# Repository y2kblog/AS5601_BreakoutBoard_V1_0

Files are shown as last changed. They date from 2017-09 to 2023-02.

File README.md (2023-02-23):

# 12bit (4096P/R) 磁気式エンコーダAS5601 Breakout Board

[English page](https://products.y2kb.com/en/as5601/latest/)

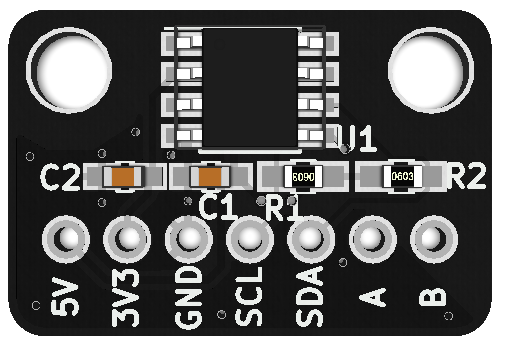
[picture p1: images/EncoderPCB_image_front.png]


## 概要

12bit (4096P/R) 分解能の磁気式アブソリュートエンコーダ AS5601 (ams AG製) を2.54mmピッチに変換する基板です。ネオジム磁石を同梱。  
5V、3.3V、GNDの電源ピンとI2C、A/B相インクリメンタル出力のピンが出ています。電源電圧は5Vもしくは3.3Vです。  
**※AS5600との違いはAS5600の出力方式がアナログ/PWM出力であるのに対し、AS5601はA/B相のインクリメンタル出力である点です。**

### AS5601の特徴
- 4096P/R の高分解能 (インクリメンタル出力は最大2048ppr)
- 磁気式のため非接触で角度計測が可能であり、信頼性と耐久性に優れている
- インターフェイス：I2C、インクリメンタル出力、PUSHピン
- I2C：設定レジスタにアクセスでき、角度の読み取りや動作設定が可能
- インクリメンタル出力：8ppr～2048pprの分解能設定が可能なA/B相の直交出力
- サンプリング時間：150μs
- AS5601とネオジム磁石の軸中心が1mm程度ずれても値の読み取りが可能

### 基板仕様
- 基板サイズ：横20mm×縦13.5ｍｍ
- 基板マウント用穴：15mmピッチ、M3×2穴
- 電源電圧に5Vを供給する場合は3.3Vピンをオープンに、3.3Vを供給する場合は5Vピンにも3.3Vを供給してください。
- PUSHピンは接続されていないためアクセスできません

## 販売  
[スイッチサイエンス委託販売ページ](https://www.switch-science.com/catalog/3494/)  
※大量注文や在庫に関する問い合わせは[こちら](mailto:info.y2kb@gmail.com)までご連絡ください。  

## 内容物
- AS5601 Breakout Board 本体
- エンコーダ用ネオジム磁石

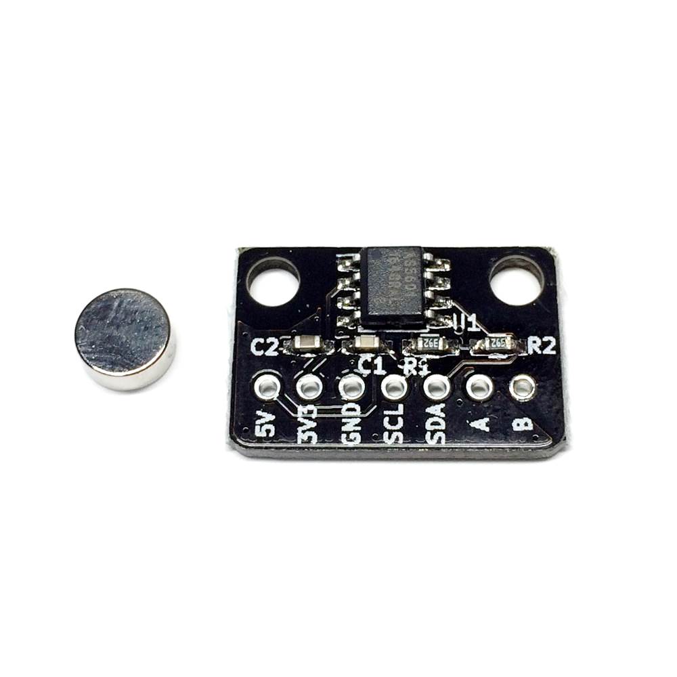
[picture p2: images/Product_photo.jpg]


### 回路図  
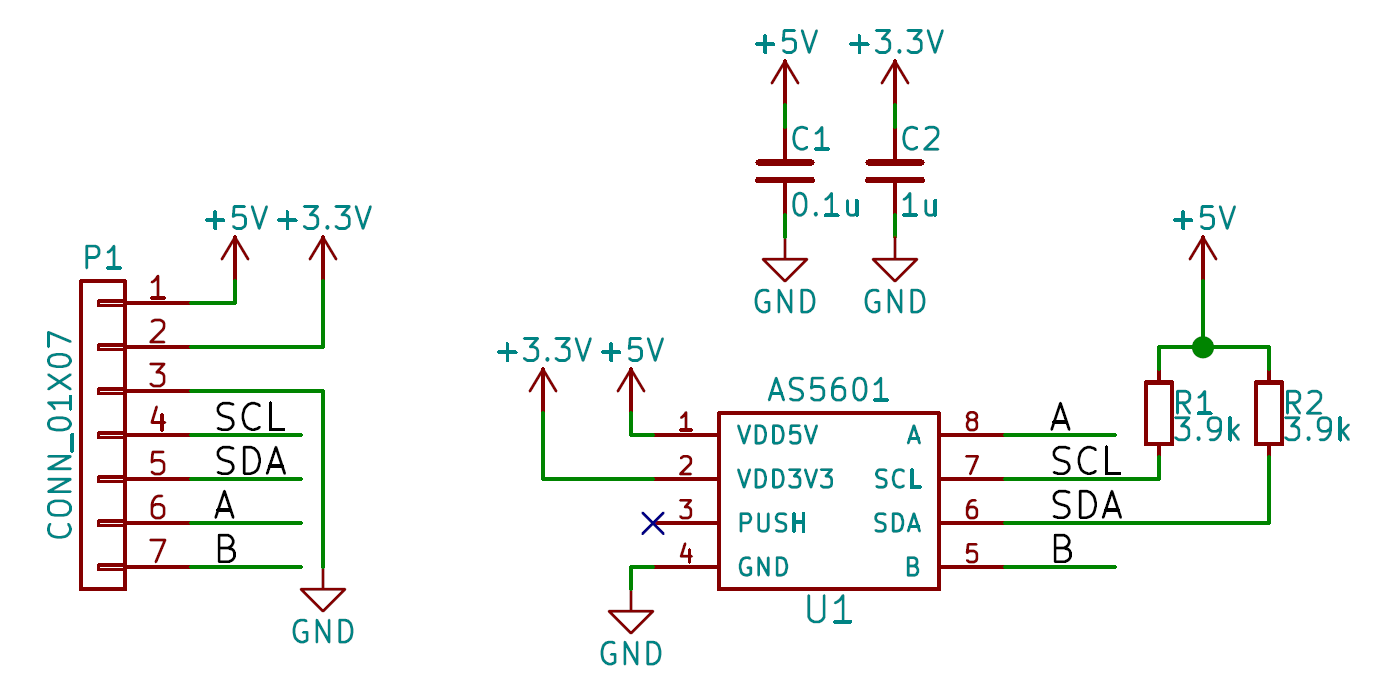
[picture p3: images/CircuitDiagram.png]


### 寸法  
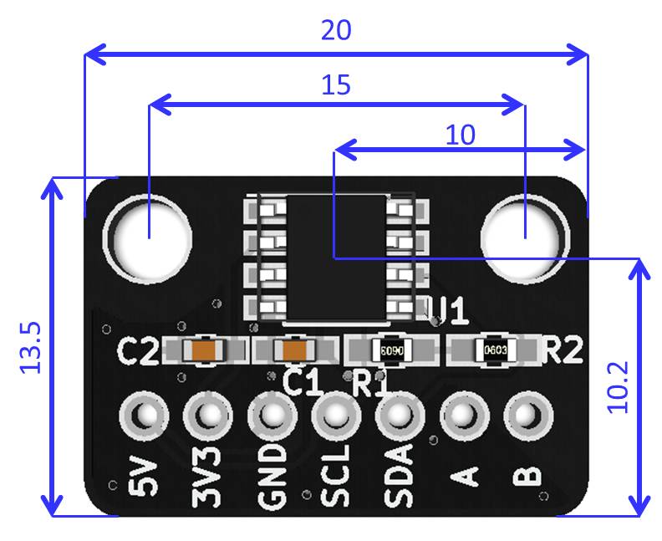
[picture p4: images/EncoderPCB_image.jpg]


## 取付方法
1. 同梱のネオジム磁石を回転体の軸中心に取り付けます
2. AS5601の中心とネオジム磁石の中心が合うよう基板を固定部に取り付けます

**取付例**  
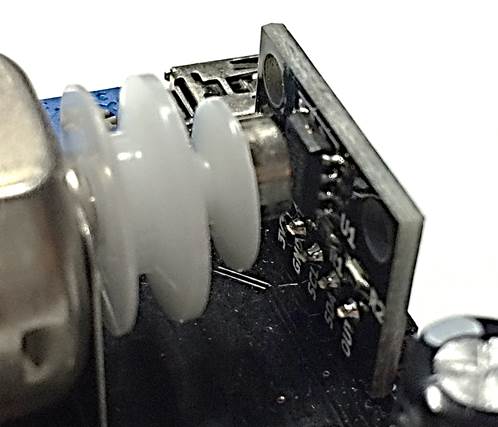
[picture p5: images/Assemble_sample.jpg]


## Arduinoによるプログラム例  

### I2Cによる角度の取得  
#### 配線図  
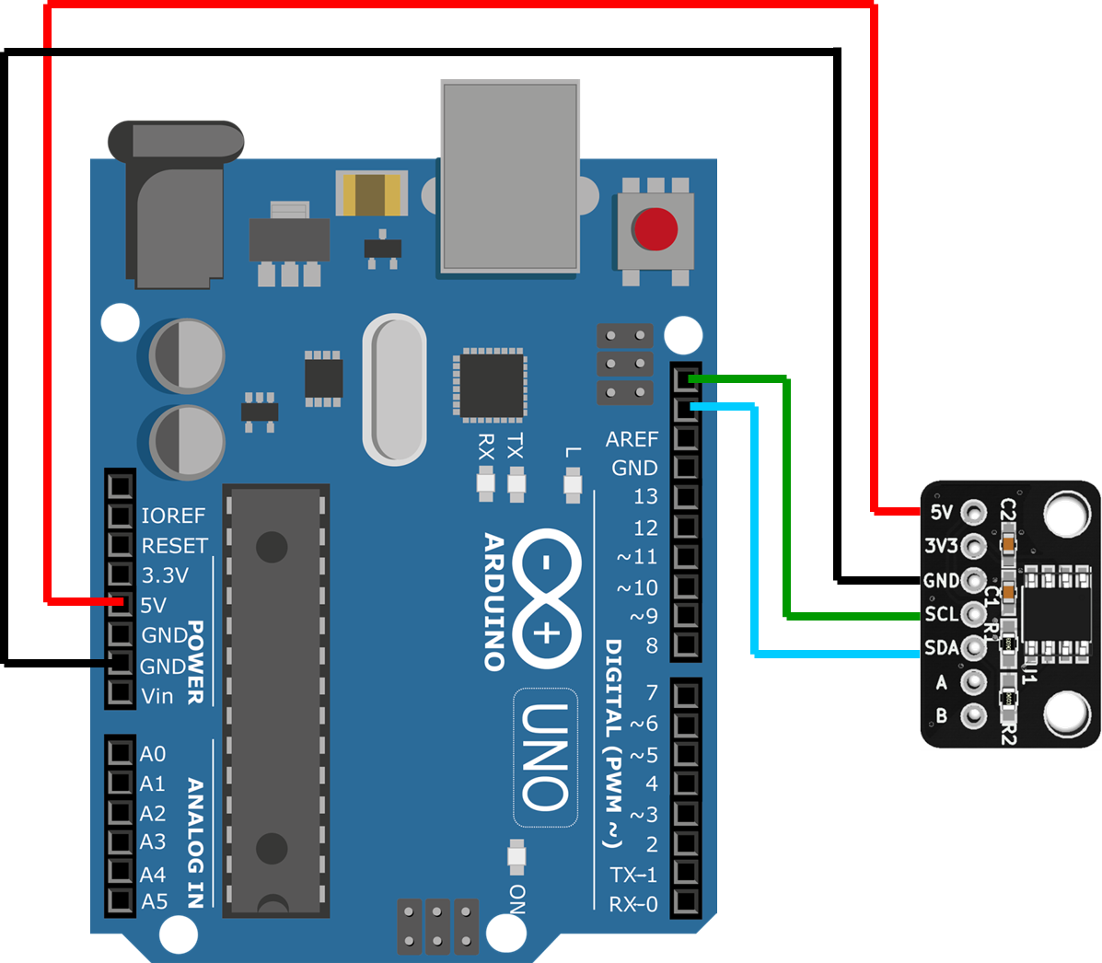
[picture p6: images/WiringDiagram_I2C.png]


#### [ソースファイル](https://github.com/y2kblog/AS5601_BreakoutBoard_V1_0/blob/master/SampleCode/Arduino/I2C_SampleCode/I2C_SampleCode.ino)

<!--
#### ソースファイルのディレクトリ  
"SampleCode/Arduino/I2C_SampleCode/I2C_SampleCode.ino"
-->

#### ミニマムコード  

```cpp
#include <stdint.h>
#include <Wire.h>
#define AS5600_AS5601_DEV_ADDRESS      0x36
#define AS5600_AS5601_REG_RAW_ANGLE    0x0C

void setup() {
  // I2C init
  Wire.begin();
  Wire.setClock(400000);

  // Read RAW_ANGLE value from encoder
  Wire.beginTransmission(AS5600_AS5601_DEV_ADDRESS);
  Wire.write(AS5600_AS5601_REG_RAW_ANGLE);
  Wire.endTransmission(false);
  Wire.requestFrom(AS5600_AS5601_DEV_ADDRESS, 2);
  uint16_t RawAngle = 0;
  RawAngle  = ((uint16_t)Wire.read() << 8) & 0x0F00;
  RawAngle |= (uint16_t)Wire.read();
  // Raw angle value (0 ~ 4095) is stored in RawAngle
}

void loop() {
}
```

### インクリメンタル出力ピンを用いた角度の取得  
#### 配線図  
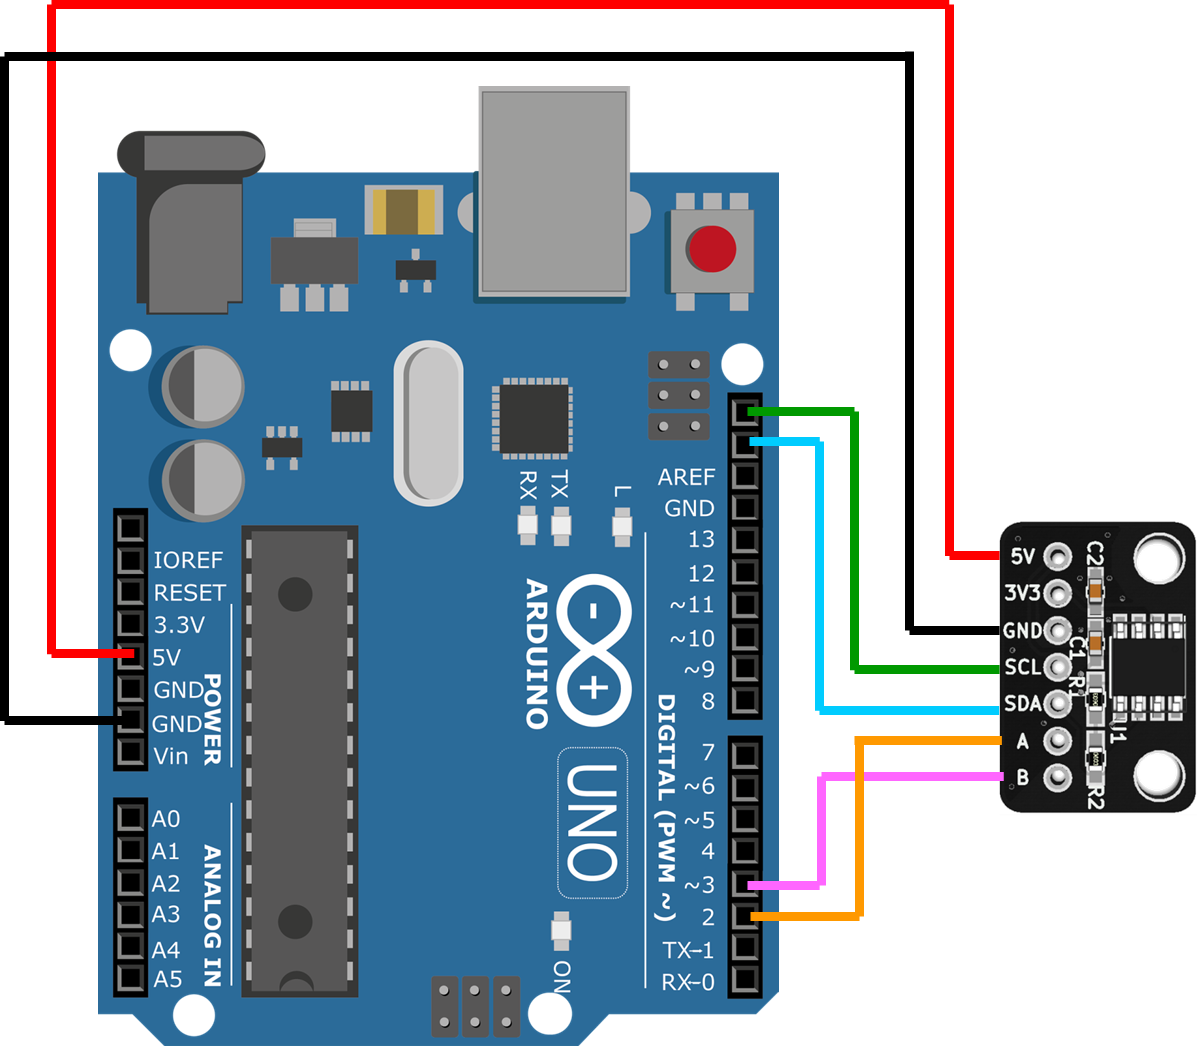
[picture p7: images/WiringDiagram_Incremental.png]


#### [ソースファイル](https://github.com/y2kblog/AS5601_BreakoutBoard_V1_0/blob/master/SampleCode/Arduino/Incremental_SampleCode/Incremental_SampleCode.ino)

<!--
#### ソースファイルのディレクトリ  
"SampleCode/Arduino/Incremental_SampleCode/Incremental_SampleCode.ino"
-->

#### ミニマムコード
```cpp
#include <stdint.h>
#include <Wire.h>
#define AS5600_AS5601_DEV_ADDRESS       0x36
#define AS5601_REG_ABN                  0x09

volatile int32_t EncoderCount;

void Encoder_GPIO_init(void) {
  DDRD  &= ~((1 << PD2) | (1 << PD3));  // Set PD2 and PD3 as input
  EICRA = 0b00000101; // Trigger event of INT0 and INT1 : Any Logic Change
  EIMSK = 0b00000011; // Enable interrupt INT0 and INT1
  sei();              //Enable Global Interrupt
}

// Encoder "A" pin logic change interrupt callback function
ISR(INT0_vect) {
  updateEncoderCount();
}

// Encoder "B" pin logic change interrupt callback function
ISR(INT1_vect) {
  updateEncoderCount();
}

void updateEncoderCount(void) {
  const static int8_t EncoderIndexTable[] =
    {0, -1, 1, 0,  1, 0, 0, -1,  -1, 0, 0, 1,  0, 1, -1, 0};
  static uint8_t EncoderPinState_Now, EncoderPinState_Prev = 0;

  EncoderPinState_Now = (PIND >> 2) & 0x03; // Bit1 : PD3 (Encoder B), Bit0 : PD2 (Encoder A)
  EncoderCount += EncoderIndexTable[EncoderPinState_Prev << 2 | EncoderPinState_Now];
  EncoderPinState_Prev = EncoderPinState_Now;
}

void Encoder_I2C_init(void) {
  // Set AS5601 resolution 2048ppr
  Wire.beginTransmission(AS5600_AS5601_DEV_ADDRESS);
  Wire.write(AS5601_REG_ABN);
  Wire.write(0b00001000);   // ABN(3:0)
  Wire.endTransmission();
  delay(1);
}

void setup() {
  // I2C init
  Wire.begin();
  Wire.setClock(400000);

  // Peripheral init
  Encoder_I2C_init();
  Encoder_GPIO_init();
}

void loop() {
  // Angle value (0 ~ 2047) is stored in EncoderCount
}
```

<!--
#### HAL (STM32)

**サンプルコード**

    // I2Cの初期化は終わっているとする

    #define AS5600_AS5601_DEV_ADDRESS      (0x36<<1)
    #define AS5600_AS5601_REG_RAW_ANGLE    0x0C

    uint8_t buf[2];
    HAL_I2C_Mem_Read(&hi2c, AS5600_AS5601_DEV_ADDRESS,
      AS5600_AS5601_REG_RAW_ANGLE, I2C_MEMADD_SIZE_8BIT,
      (uint8_t*)buf, 2, 1000);
    uint16_t RawAngle;
    RawAngle = (uint16_t) buf[0] << 8 | (uint16_t) buf[1];
    RawAngle &= 0x0FFF;
    // Raw angle value (0x0000~0x0FFF) is stored in RawAngle

### コンフィグのメモリへの焼き付け  

-->

### 設定レジスタの焼き付けによる分解能の固定

AS5601のデフォルトの分解能は8pprなので、初期状態ですと電源投入毎に分解能を設定する必要があります。
そこで、分解能を2048pprに設定後にBurn_Settingコマンドにより設定レジスタを焼くことで、電源を落として再度電源を投入しても起動時から2048pprに設定された状態で固定され、I2Cにより分解能等の設定情報を再設定する必要がなくなります。  
**※一度書き込むと以後分解能やフィルタ設定などを変更することはできなくなります。**

サンプルコードは[こちら](https://github.com/y2kblog/AS5601_BreakoutBoard_V1_0/blob/master/SampleCode/Arduino/burnConfig_SampleCode/burnConfig_SampleCode.ino)。

## 資料

- 2Dデータ(DXF)：<a href="https://github.com/y2kblog/AS5601_BreakoutBoard_V1_0/raw/master/PCB_source/dxf/AS5601_BreakoutBoard_V1_0_dxf.zip" download="">AS5601_BreakoutBoard_V1_0_dxf.zip</a>  
- 3Dデータ(STEP)：<a href="https://github.com/y2kblog/AS5601_BreakoutBoard_V1_0/raw/master/PCB_source/step/AS5601_BreakoutBoard_V1_0_step.zip" download="">AS5601_BreakoutBoard_V1_0_step.zip</a>  

## License
MIT License

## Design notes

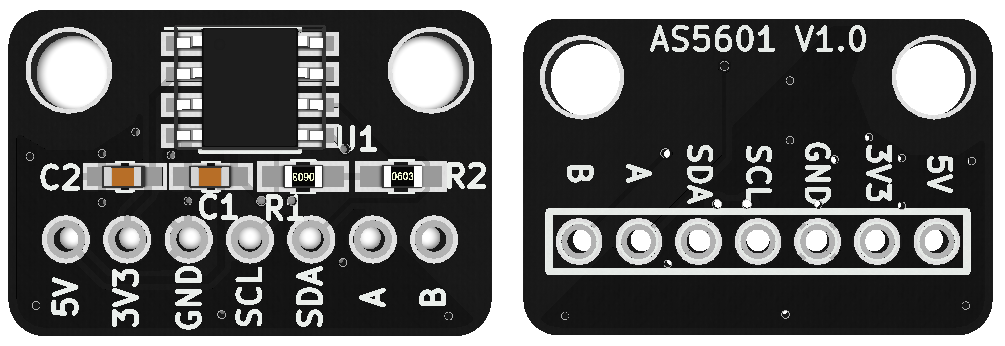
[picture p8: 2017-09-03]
images/EncoderPCB_image_BothSide.png

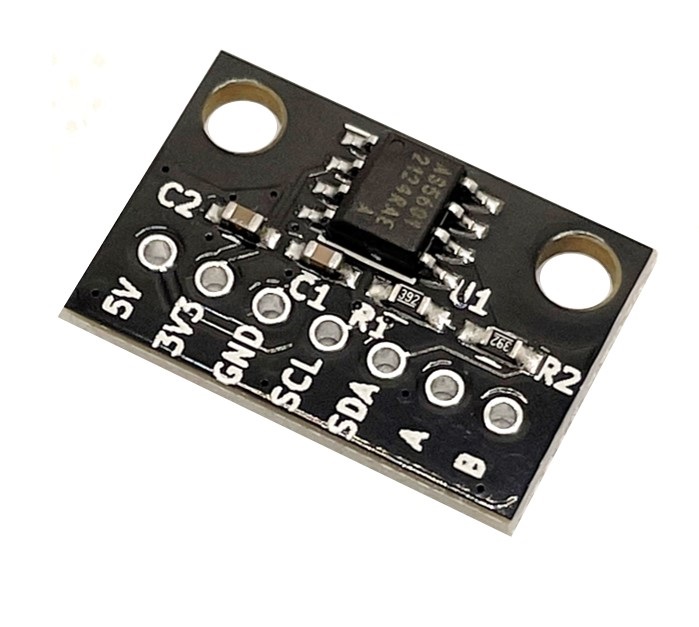
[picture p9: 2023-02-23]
images/product-image.jpg

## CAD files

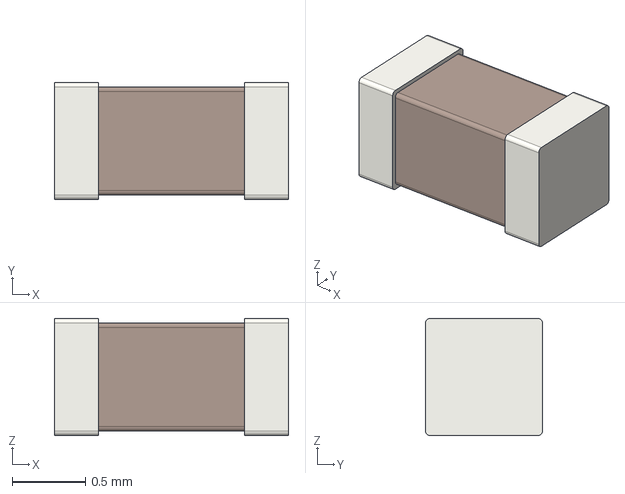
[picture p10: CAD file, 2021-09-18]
PCB_source/3d/C_0603_1608Metric.step
1.60 x 0.8 x 0.8 mm

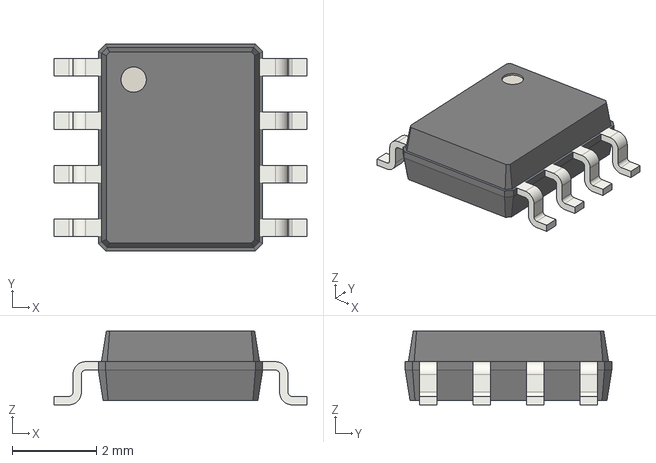
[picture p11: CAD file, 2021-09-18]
PCB_source/3d/SOIC-8_3.9x4.9mm_P1.27mm.step
6.00 x 4.90 x 1.75 mm

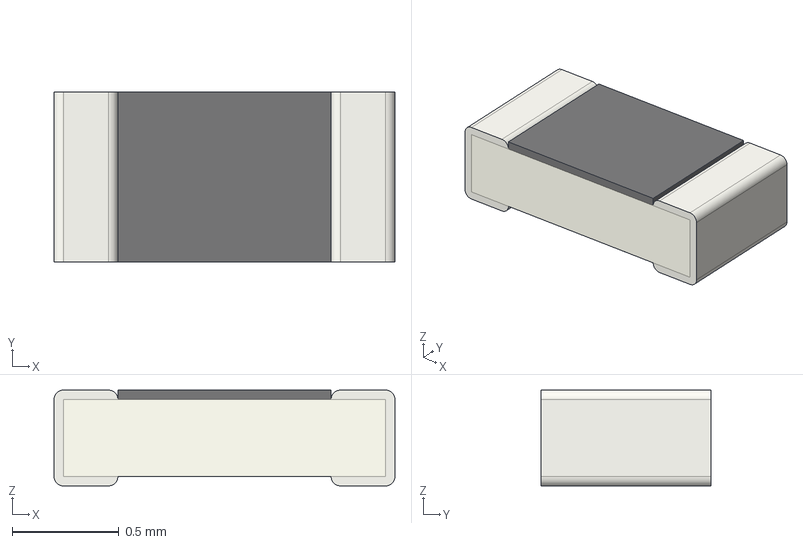
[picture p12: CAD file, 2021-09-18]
PCB_source/3d/R_0603_1608Metric.step
1.60 x 0.8 x 0.45 mm

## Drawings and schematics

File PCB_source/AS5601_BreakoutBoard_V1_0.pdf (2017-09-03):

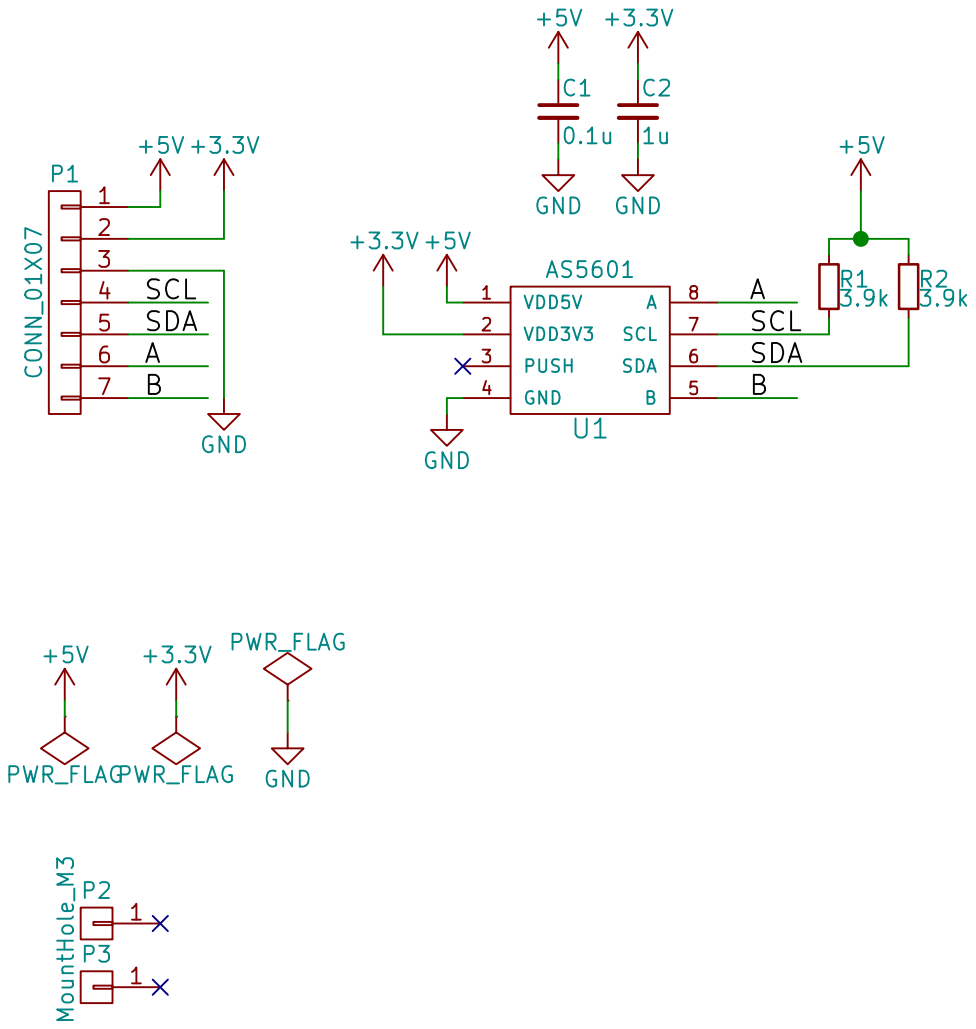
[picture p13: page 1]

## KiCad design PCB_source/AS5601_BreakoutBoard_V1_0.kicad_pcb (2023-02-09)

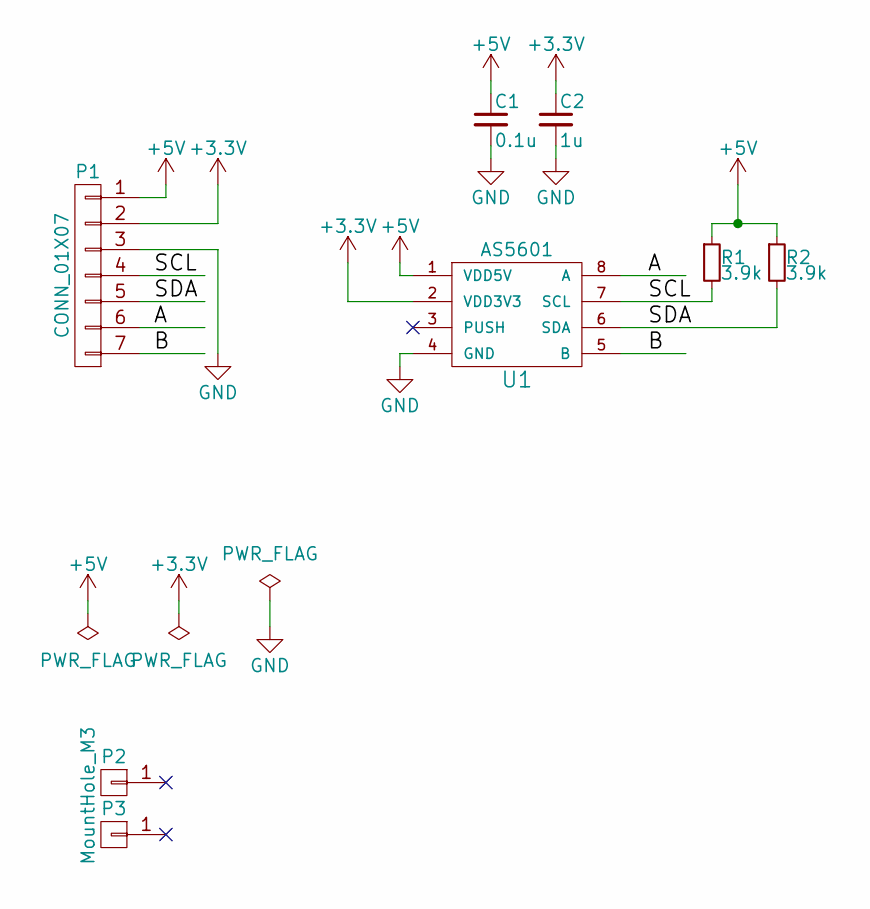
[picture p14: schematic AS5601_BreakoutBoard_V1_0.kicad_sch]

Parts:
C1: 0.1u; C_0603_HandSoldering
C2: 1u; C_0603_HandSoldering
P1: CONN_01X07; USER_SIL-7
P2, P3: MountHole_M3; MountingHole_3.2mm_M3
R1, R2: 3.9k; R_0603_HandSoldering
U1: AS5601; SOIC-8_3.9x4.9mm_Pitch1.27mm

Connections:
+3V3: C2.1, P1.2, U1.2 (VDD3V3)
+5V: C1.1, P1.1, R1.1, R2.1, U1.1 (VDD5V)
/A: P1.6, U1.8 (A)
/B: P1.7, U1.5 (B)
/SCL: P1.4, R1.2, U1.7 (SCL)
/SDA: P1.5, R2.2, U1.6 (SDA)
GND: C1.2, C2.2, P1.3, U1.4 (GND)

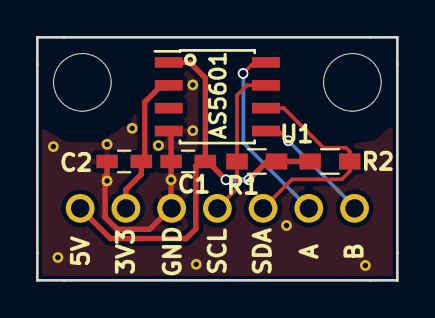
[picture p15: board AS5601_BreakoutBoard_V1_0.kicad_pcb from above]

Board: 2 copper layers, 20.0 x 13.5 mm, 19 parts (1 on the bottom side), 7 nets.

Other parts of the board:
11, 12, 21, 22, 31, 32, 41, 41#2, 42, 51, 52: USER_GNDvia

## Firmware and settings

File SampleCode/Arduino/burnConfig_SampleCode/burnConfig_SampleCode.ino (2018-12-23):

/* ----- Pin setting -----
   PC4 - Analog   4 - Encoder SDA
   PC5 - Analog   5 - Encoder SCL
   PD2 - Digital  2 - Encoder A - INT0
   PD3 - Digital  3 - Encoder B - INT1
*/

#include <stdint.h>
#include <Wire.h>
#define AS5600_AS5601_DEV_ADDRESS       0x36
#define AS5600_AS5601_REG_CONF          0x07
#define AS5600_AS5601_REG_STATUS        0x0B
#define AS5601_REG_ABN                  0x09
#define AS5600_AS5601_REG_BURN          0xFF

volatile int32_t EncoderCount;

void Encoder_GPIO_init(void) {
  DDRD  &= ~((1 << PD2) | (1 << PD3));  // Set PD2 andEncoder_burn_config PD3 as input
  EICRA = 0b00000101; // Trigger event of INT0 and INT1 : Any Logic Change
  EIMSK = 0b00000011; // Enable interrupt INT0 and INT1
  sei();              //Enable Global Interrupt
}

// Encoder "A" pin logic change interrupt callback function
ISR(INT0_vect) {
  updateEncoderCount();
}

// Encoder "B" pin logic change interrupt callback function
ISR(INT1_vect) {
  updateEncoderCount();
}

void updateEncoderCount(void) {
  const static int8_t EncoderIndexTable[] =
    {0, -1, 1, 0,  1, 0, 0, -1,  -1, 0, 0, 1,  0, 1, -1, 0};
  static uint8_t EncoderPinState_Now, EncoderPinState_Prev = 0;

  EncoderPinState_Now = (PIND >> 2) & 0x03; // Bit1 : PD3 (Encoder B), Bit0 : PD2 (Encoder A)
  EncoderCount += EncoderIndexTable[EncoderPinState_Prev << 2 | EncoderPinState_Now];
  EncoderPinState_Prev = EncoderPinState_Now;
}

void Encoder_I2C_init(void) {
  byte error;
  uint8_t data;

  // Read AS5601 status register
  Wire.beginTransmission(AS5600_AS5601_DEV_ADDRESS);
  Wire.write(AS5600_AS5601_REG_STATUS);
  Wire.endTransmission(false);
  Wire.requestFrom(AS5600_AS5601_DEV_ADDRESS, 1);
  data = Wire.read();
  data &= 0x38;
  /*
  if (data != 0x20)
  {
    Serial.print("Magnet error : ");
    if ( !(data & 0x20) )
      Serial.println("Magnet was not detected");
    if (data & 0x10)
      Serial.println("Magnet too weak");
    if (data & 0x08)
      Serial.println("Magnet too strong");
    Serial.println("Stop");
    for (;;);
  }
  else
    Serial.println("Magnet : OK");
    */

  // Set AS5601 resolution 2048ppr
  Serial.println("Change Encoder resolution 2048ppr");
  Wire.beginTransmission(AS5600_AS5601_DEV_ADDRESS);
  Wire.write(AS5601_REG_ABN);
  Wire.write(0b00001000);   // Resolution:2048ppr(ABN=0b1000)
  error = Wire.endTransmission();
  if (error){
    Serial.print("error=");Serial.println(error);
  }
  delay(1);

  // Write AS5601 conf
  Wire.beginTransmission(AS5600_AS5601_DEV_ADDRESS);
  Wire.write(AS5600_AS5601_REG_CONF);
  Wire.write(0b00000111);   // Watchdog Timer:Off(WD=0b0), Fast Filter Threshold:6LSBs(FTH = 0b001), Slow Filter:2x(SF = 0b11)
  error = Wire.endTransmission();
  if (error){
    Serial.print("error=");Serial.println(error);
  }
  delay(1);
}

///// CAUTION: One time programming!!! //////
void Encoder_burn_config(void) {
  byte error;
  // Burn conf
  Wire.beginTransmission(AS5600_AS5601_DEV_ADDRESS);
  Wire.write(AS5600_AS5601_REG_BURN);
  Wire.write(0x40);   // Burn_Setting = 0x40
  error = Wire.endTransmission();
  if (error){
    Serial.print("error=");Serial.println(error);
  }
  delay(1);
}

void setup() {
  // I2C init
  Wire.begin();
  Wire.setClock(400000);

  // Communication function init
  Serial.begin(115200);
  while (!Serial);

  // Peripheral init
  Encoder_I2C_init();
  Encoder_burn_config();  // CAUTION: One time programming!
  Encoder_GPIO_init();
}

void loop() {
  Serial.println(EncoderCount);
  delay(200);
}

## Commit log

2017-09-07 fix sample code bug
    [Arduino_AS5600_AS5601_SampleCode.ino]
2017-09-17 Add sample code using Incremental output
2017-09-22 Add circuit diagram
2018-05-28 Add burnConfig sample code
    [burnConfig_SampleCode.ino]
2021-09-18 add step and refactoring
    [AS5601_BreakoutBoard_V1_0-2021-09-18-11-56-55.sch, AS5601_BreakoutBoard_V1_0.dsn, AS5601_BreakoutBoard_V1_0.kicad_pcb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]
2023-02-09 kicad v6
    [AS5601_BreakoutBoard_V1_0.kicad_pcb, AS5601_BreakoutBoard_V1_0.kicad_sch]

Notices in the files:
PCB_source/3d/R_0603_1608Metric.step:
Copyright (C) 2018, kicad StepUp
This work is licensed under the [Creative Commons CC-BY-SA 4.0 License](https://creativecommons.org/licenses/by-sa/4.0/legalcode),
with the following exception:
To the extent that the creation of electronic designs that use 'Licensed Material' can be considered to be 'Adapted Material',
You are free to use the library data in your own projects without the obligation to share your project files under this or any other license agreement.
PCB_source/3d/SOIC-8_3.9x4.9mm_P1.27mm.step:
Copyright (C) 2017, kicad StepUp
